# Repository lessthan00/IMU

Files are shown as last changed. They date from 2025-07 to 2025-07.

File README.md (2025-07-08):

# IMU  

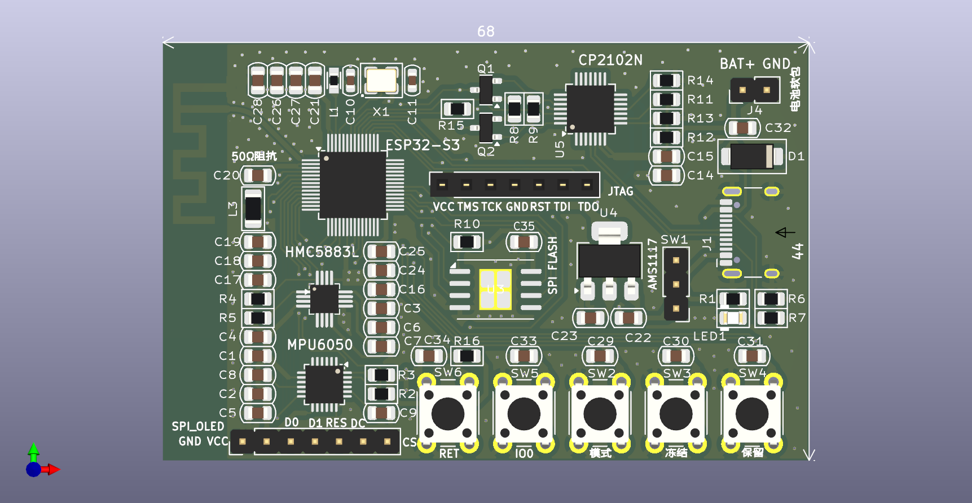
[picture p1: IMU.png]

  
## 基于ESP32的IMU系统与OLED显示屏  
  
### 简介  
  
本项目实现了一个基于ESP32微控制器的惯性测量单元（IMU）系统，集成了MPU6050（6轴加速度计和陀螺仪）、HMC5883L（3轴磁力计）和SSD1306 OLED显示屏（128x64像素）。系统通过卡尔曼滤波融合传感器数据，实时计算并显示设备的俯仰（pitch）、滚转（roll）和偏航（yaw）角度，适用于机器人、无人机或可穿戴设备等需要精确姿态测量的场景。  
  
### 硬件要求  
  
#### 元件清单  
  
| 元件 | 描述 | 备注 |  
|---|---|---|
| ESP32微控制器 | ESP32开发板（如DevKitC）或ESP32S3芯片 | ESP32S3需USB转串口烧录 |  
| MPU6050传感器模块 | 6轴加速度计和陀螺仪 | I2C通信，地址0x68或0x69 |  
| HMC5883L传感器模块 | 3轴数字磁力计 | I2C通信，地址0x1E |  
| SSD1306 OLED显示屏 | 128x64像素 | I2C通信 |  
| 触控按钮（4个） | 用于电源、模式、冻结和预留功能 | 连接到GPIO 15、16、17、18 |  
| 跳线 | 用于连接元件 | |  
| 面包板或PCB | 用于安装元件 | |  
| 电源 | 若不使用带USB的开发板需单独电源 | 3.3V |  
| USB转串口转换器 | 如CP2102或CH340，仅ESP32S3芯片需要 | 用于程序烧录 |  
  
#### 引脚接线图  
  
所有传感器和显示屏通过I2C接口连接到ESP32的GPIO 21（SDA）和GPIO 22（SCL）。按钮连接到指定GPIO引脚。以下是详细接线表：  
  
| 元件 | 引脚 | ESP32连接 | 备注 |  
|---|---|---|---|
| MPU6050 | SDA  | GPIO 11 | I2C数据线 |  
| MPU6050 | SCL  | GPIO 12 | I2C时钟线 |  
| MPU6050 | VCC  | 3.3V | 电源 |  
| MPU6050 | GND  | GND | 接地 |  
| HMC5883L | SDA  | GPIO 11 | I2C数据线 |  
| HMC5883L | SCL  | GPIO 12 | I2C时钟线 |  
| HMC5883L | VCC  | 3.3V | 电源 |  
| HMC5883L | GND  | GND | 接地 |  
| SSD1306 OLED | SDA  | GPIO 11 | I2C数据线 |  
| SSD1306 OLED | SCL  | GPIO 12 | I2C时钟线 |  
| SSD1306 OLED | VCC  | 3.3V | 电源 |  
| SSD1306 OLED | GND  | GND | 接地 |  
| 电源按钮 | - | GPIO 15 | 控制电源开关 |  
| 模式按钮 | - | GPIO 16 | 切换绝对/相对模式 |  
| 冻结按钮 | - | GPIO 17 | 冻结/解冻显示 |  
| 预留按钮 | - | GPIO 18 | 预留未来功能 |  
  
**ESP32S3芯片额外接线**（若使用芯片而非开发板）：  
- TX（ESP32S3）→ RX（USB转串口）  
- RX（ESP32S3）→ TX（USB转串口）  
- CH_PD（ESP32S3）→ 3.3V（USB转串口）  
- EN（ESP32S3）→ 3.3V（USB转串口）  
- GND（ESP32S3）→ GND（USB转串口）  
- VCC（ESP32S3）→ 3.3V（USB转串口）  
  
**注意**：所有I2C设备（MPU6050、HMC5883L、SSD1306）共享相同的SDA和SCL线。按钮连接需使用内部上拉电阻或外部上拉电阻。  
  
### 软件结构  
  
#### 程序结构框图  
  
软件基于FreeRTOS实现多任务处理，包含以下并发任务：  
- **传感器任务**：以20 Hz频率从MPU6050和HMC5883L读取数据，发送到传感器队列。  
- **处理任务**：从传感器队列接收数据，使用卡尔曼滤波计算姿态（俯仰、滚转、偏航），以5 Hz频率发送到姿态队列。  
- **显示任务**：从姿态队列接收数据，以5 Hz频率更新OLED显示屏。  
- **按钮任务**：监控按钮状态，处理电源开关、模式切换（绝对/相对）和显示冻结。  
- **初始化与校准任务**：启动时初始化I2C接口、传感器，并执行校准。  
  
**框图描述**：  
- **输入**：MPU6050（加速度、角速度）、HMC5883L（磁场）  
- **任务流程**：  
  - 传感器任务 → 传感器队列 → 处理任务 → 姿态队列 → 显示任务  
  - 按钮任务 → 处理用户输入  
- **输出**：SSD1306 OLED显示屏  
- **同步机制**：使用FreeRTOS队列（`sensor_queue`、`attitude_queue`）和信号量（`i2c_mutex`、`ssd1306_mutex`、`calibration_done_sem`）进行任务间通信和资源保护。  
  
#### 流程图  
  
1. **启动**：  
   - 初始化ESP32S3外设（I2C、GPIO）  
   - 创建FreeRTOS任务和队列  
2. **校准**：  
   - 校准MPU6050（加速度计和陀螺仪，设备需静止）  
   - 校准HMC5883L（磁力计，需缓慢旋转设备）  
3. **主循环**：  
   - 传感器任务：持续读取传感器数据并发送到队列  
   - 处理任务：从队列接收数据，处理并发送到显示队列  
   - 显示任务：从队列接收数据，更新显示屏  
   - 按钮任务：持续监控按钮并处理事件  
4. **关机**：  
   - 长按电源按钮，暂停任务并关闭系统  
  
### 传感器与显示屏简介  
  
#### MPU6050  
  
MPU6050是一个6轴惯性测量单元，包含3轴加速度计（量程±4g）和3轴陀螺仪（量程±500 dps）。它通过I2C通信（地址0x68或0x69），用于测量设备的俯仰和滚转角度。更多信息可参考 [MPU6050教程](https://www.instructables.com/Connecting-MPU6050-With-ESP32/)。  
  
#### HMC5883L  
  
HMC5883L是一个3轴数字磁力计，用于测量磁场以确定偏航（罗盘方向）。它通过I2C通信（地址0x1E），支持倾斜补偿以提高精度。更多信息可参考 [HMC5883L与ESP32接口](https://circuitdigest.com/microcontroller-projects/diy-smartwatch-using-esp32-part3-interfacing-magnetometer-and-gyroscope-with-esp32)。  
  
#### SSD1306 OLED显示屏  
  
SSD1306是一个128x64像素的OLED显示屏，通过I2C通信，显示实时传感器数据，包括俯仰、滚转、偏航、加速度、陀螺仪和磁力计读数。支持绝对和相对模式，并可根据Z轴加速度自动翻转显示。更多信息可参考 [ESP32与SSD1306教程](https://randomnerdtutorials.com/esp32-ssd1306-oled-display-arduino-ide/)。  
  
### 使用说明  
  
#### 硬件设置  
  
1. 按照引脚接线图连接MPU6050、HMC5883L、SSD1306和按钮到ESP32S3。  
2. 若使用ESP32S3芯片，连接USB转串口模块（TX、RX、CH_PD、EN、GND）。  
3. 使用面包板或PCB固定元件，确保3.3V电源稳定。  
  
#### 程序烧录  
  
1. **使用ESP32S3开发板**：  
   - 通过USB连接开发板到计算机。  
   - 使用ESP-IDF或Arduino IDE（需安装ESP32支持）上传`main.c`程序。  
2. **使用ESP32S3芯片**：  
   - 连接USB转串口模块（如CP2102或CH340）。  
   - 使用ESP-IDF或Arduino IDE烧录程序，确保正确配置串口引脚。  
  
#### 操作  
  
- **开机**：短按电源按钮（GPIO 15）。  
- **关机**：长按电源按钮（>2秒）。  
- **模式切换**：按模式按钮（GPIO 16）切换绝对/相对测量模式。  
- **冻结显示**：按冻结按钮（GPIO 17）冻结/解冻显示。  
- **预留功能**：预留按钮（GPIO 18）为未来功能保留。  
  
### 调试与日志  
  
- 系统使用ESP_LOG框架记录日志，标签为“mpu6050 test”和“SSD1306”。  
- 定期记录任务堆栈使用情况以监控内存使用。  
- 校准期间需保持设备静止（MPU6050）或缓慢旋转（HMC5883L）。  
  
### 当前存在的问题  
  
1. **数据更新速度慢**：  
   - 传感器任务以20 Hz频率生成数据，而处理任务和显示任务以5 Hz频率消费数据，导致生产速度快于消费速度，可能造成`sensor_queue`和`attitude_queue`队列满溢。日志中会记录“传感器队列已满”或“姿态队列已满”的警告。  
   - **潜在解决方案**：优化处理任务的计算效率（如简化卡尔曼滤波算法）或增加队列大小，同时调整任务调度优先级以平衡生产和消费速度。  
  
2. **关机后无法正常开机**：  
   - 系统运行一段时间后，关机（长按电源按钮）并再次短按电源按钮可能无法正常开机，表现为任务未正确恢复或系统未完全初始化。  
   - **潜在原因**：可能是任务挂起/恢复逻辑问题，或电源管理状态未正确重置。需要检查`button_task`中的任务恢复逻辑和硬件电源管理电路。  
  
### 未来展望  
  
1. **添加可视化更好的仪表界面**：  
   - 当前SSD1306显示屏以文本形式显示数据，未来计划开发图形化仪表界面（如指针式仪表或3D姿态可视化），以提高用户体验。  
   - 实现方式可能包括使用SSD1306的图形库绘制动态仪表盘，或升级到更高分辨率的显示屏（如SSD1327或彩色TFT屏）以支持更复杂的可视化。  
   - 需优化显示任务以确保图形渲染不影响实时性能。  
  
## 硬件从新设计  
  
### 物料  
  
GY-521模块,MPU6050,接口定义VCC,GND,SCL,SDA,XDA,SCL,ADO,INT  
GY-271模块,HMC5883L,接口定义VCC,GND,SCL,SDA,DRDY  
轻触开关  
0.96寸OLED SSD1306模块,接口定义VCC,GND,SCL,SDA  
因为I2C总线的通讯拥挤,可以选择使用SPI通讯.  
0.96村OLED SSD1306模块,7针接口定义 GND,VCC,D0,D1,RES,DC,CS  
GND 电源地, VCC 3.3V~5V, D0, SPI时钟线(SPI_CLK), D1,SPI数据线(SPI_MOSI), RES,复位, DC, 数据/命令选择脚,CS,片选信号,低电平有效,CS不可悬空.  
CH340G  
ESP32-S3FN8  
ESP32-S3-WROOM-1-N16R8  
  
### [H/W 硬件参考](https://docs.espressif.com/projects/esp-idf/zh_CN/stable/esp32s3/hw-reference/index.html)  
  
[技术参考手册 (PDF)](https://www.espressif.com/sites/default/files/documentation/esp32-s3_technical_reference_manual_cn.pdf)  
[技术规格书 (PDF)](https://www.espressif.com/sites/default/files/documentation/esp32-s3_datasheet_cn.pdf)  
  
### SPI分配  
  
### [SPI2 管脚对应表](https://docs.espressif.com/projects/esp-idf/zh_CN/stable/esp32s3/api-reference/peripherals/spi_master.html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)  
  
| 管脚名称  | GPIO编号 (SPI2) |  
|---|---|
| CS0 | 10 |  
| SCLK | 12 |  
| MISO | 13 |  
| MOSI | 11 |  
| QUADWP | 14 |  
| QUADHD | 9 |  
  
#### [技术规格书 (PDF)](https://www.espressif.com/sites/default/files/documentation/esp32-s3_datasheet_cn.pdf)  
  
##### 第 30 章 SPI 控制器(SPI)  
  
##### 30.1 概述  
  
串行外设接口(SPI)是一种同步串行接口，可用于与外围设备进行通信。ESP32-S3芯片集成了四个SPI控制  
器：  
• SPI0  
 • SPI1  
 • 通用SPI2，即GP-SPI2  
 • 和通用SPI3，即GP-SPI3  
 SPI0 和 SPI1 控制器主要供内部使用以访问外部flash及PSRAM。本章节主要介绍GP-SPI控制器，即GP-SPI2  
和GP-SPI3。  
  
(所以毫无疑问应该选择SPI2)  
  
##### 30.5.8.3 主机全双工通信（仅支持1-bit模式）  
  
| Master (GP-SPI2) | Direction | Slave  |  
|---|---|---|
| FSPID | → | MOSI |  
| FSPIQ | ← | MISO |  
| FSPICLK | → | CLK |  
| FSPICS0 | → | CS |  
  
##### 附录A–ESP32-S3管脚总览  
  
GPIO9 ~ GPIO14 并未高亮,说明无限制和关键作用,可以放心使用.  
  
### I2C 分配  
  
[技术规格书 (PDF)](https://www.espressif.com/sites/default/files/documentation/esp32-s3_datasheet_cn.pdf)  
  
#### 4.2.1.2 I2C 接口  
  
管脚分配  
I2C 的管脚可以为任意GPIO，通过GPIO交换矩阵配置。  
  
#### 2.3.1 IO MUX 功能  
  
部分直接源自特定外设（U0TXD、MTCK等），包括UART0/1、JTAG、SPI0/1和SPI2  
  
(意味着I2C 并没有不通过IO MUX 矩阵的更特殊接口)  
  
RTC_GPIO0,RTC_GPIO3均被标记为黄色  
  
#### [技术参考手册 (PDF)](https://www.espressif.com/sites/default/files/documentation/esp32-s3_technical_reference_manual_cn.pdf)2.3.4 GPIO 和RTC_GPIO 的限制  
  
本章节的表格中，部分管脚功能有高亮标记。推荐优先使用没有高亮的GPIO或RTC_GPIO管脚。  
如需更多管脚，请谨慎选择高亮的GPIO或RTC_GPIO管脚，避免与重要功能冲突。  
  
#### [技术规格书 (PDF)](https://www.espressif.com/sites/default/files/documentation/esp32-s3_datasheet_cn.pdf)附录A–ESP32-S3管脚总览  
  
可知标黄原因:  
GPIO0,复位时IE,WPU,复位后IE,WPU.  
GPIO3,复位时IE,复位后IE.  
  
#### Boot 模式控制  
  
复位释放后，GPIO0、GPIO1、GPIO2和GPIO46在复位时的值将共同决定Boot模式。表8.2-1列出了GPIO0、  
GPIO1、GPIO2 和 GPIO46 的 Strapping 值及其对应的系统启动模式。  
表8.2-1. 系统启动模式  
  
| Boot Mode | GPIO0 | GPIO46 | GPIO1 | GPIO2 |  
|---|---|---|---|---|
| SPI Boot Mode | 1 | x | x | x |  
| Joint Download Boot Mode| 0 | 0 | x | x |  
| SPI Download Boot Mode  | 0 | 1 | 1 | 0 |  
  
x：任何取值均不会对结果有影响，因此可忽略。  
Joint Download Boot 模式下支持以下下载方式：  
• USB Download Boot  
   –USB-Serial-JTAG Download Boot  
   –USB-OTG Download Boot  
• UART Download Boot  
SPI DownloadBoot模式：GPIO1和GPIO2不是strapping管脚，但使用SPI Download Boot 模式时需要预留GPIO1和GPIO2。GPIO1和GPIO2默认浮空，在复位时处于高阻抗状态。  
  
在SPI Boot 模式下，ROM引导加载程序通过从SPIflash中读取程序来启动系统。SPIBoot模式可进一步细分为以下两种启动方式：  
• 常规flash启动方式：支持安全启动。ROM引导加载程序将程序从flash加载到SRAM，并执行。在大多数实际应用场景中，上述执行的程序多为二级引导程序，该二级引导程序将启动最终的应用程序。  
• 直接启动方式：不支持安全启动，程序直接从flash中运行。如需使能这一启动方式，请确保下载至flash的bin 文件其前两个字（地址：0x42000000）为0xaedb041d。  
在Joint Download Boot 模式下，用户可通过UART或USB接口将二进制文件下载至flash，或将二进制文件下载至SRAM并在SRAM中运行程序。  
在SPI Download Boot 模式下，用户可通过SPI接口将二进制文件下载至flash，或将二进制文件下载至SRAM并运行SRAM中的程序.  
  
所以GPIO0 GPIO1 GPIO2 GPIO3都最好不使用.  
  
#### 管脚配置一栏为复位时和复位后预设配置缩写  
  
•IE–输入使能  
•WPU–内部弱上拉电阻使能  
•WPD–内部弱下拉电阻使能  
• USB_PU–USB上拉电阻使能–USB管脚（GPIO19和GPIO20）默认开启USB功能，此时管脚是否上拉由USB上拉决定。USB上拉由USB_SERIAL_JTAG_DP/  
 DM_PULLUP控制，USB上拉电阻的具体阻值可通过USB_SERIAL_JTAG_PULLUP_VALUE位控制，详见《ESP32-S3技术参考手册》  
>章节USB串口/JTAG控制器。–USB管脚关闭USB功能时，用作普通GPIO，默认禁用管脚内部弱上/下拉电阻，可通过IO_MUX_FUN_WPU/WPD配置，  
详见《ESP32-S3技术参考手册》>章节IOMUX和GPIO交换矩阵。  
EFUSE_DIS_PAD_JTAG的值为  
• 0-弱上拉电阻使能  
• 1-管脚浮空  
  
### SSD1306 7PIN design  
  
[taobao](https://pan.baidu.com/s/1WhZjZDjIXnzRosZPsYRTPA?pwd=6666 )  
  
0.96村OLED SSD1306模块,7针接口定义 GND,VCC,D0,D1,RES,DC,CS  
  
| 引脚名称  | 描述 | 备注 |  
|---|---|---|
| GND | 电源地 | |  
| VCC | 电源 (3.3V~5V) | 工作电压范围 |  
| D0 | SPI时钟线 (SPI_CLK) | |  
| D1 | SPI数据线 (SPI_MOSI) | |  
| RES | 复位信号 | |  
| DC | 数据/命令选择脚 | |  
| CS | 片选信号 (低电平有效) | 不可悬空 |  
  
### MPU6050 design  
  
copy from  [MPU6050](https://github.com/lessthan00/MPU6050)  
  
[JLC 页面](https://www.jlc-smt.com/lcsc/detail?componentCode=C24112)  
  
再次对比原理图封装无问题.  
对比芯片封装也无问题, 引脚间距0.5, QFN4x4mm, 热焊盘2.7x2.7, 打大过孔, 拉长焊盘,好焊接.  
  
[data sheet](https://item.szlcsc.com/datasheet/MPU-6050/24852.html)  
  
#### 描述  
  
其数字运动处理器(DMP)提供的融合运动数据输出，大幅降低了对系统处理器频繁轮询传感器数据的需求。  
1024字节片上FIFO缓冲区通过让系统处理器突发读取传感器数据后进入低功耗模式，有效降低系统整体功耗。  
封装 4x4x0.9mm(QFN)  
MPU-6050仅支持I2C串行接口且设有独立VLOGIC引脚；  
3轴陀螺仪、3轴加速度计及数字运动处理器™(DMP)。通过专用I2C传感器总线，可直接接入外部3轴电子罗盘数据，输出完整的9轴MotionFusion™融合数据。  
  
#### 7.2 Typical Operating Circuit  
  
对比电路图无问题,对比封装,无问题.  
  
I2C 上拉电阻10K  
AD0 下拉到地, 简化电路, 固定I2C 地址.  
FSYNC 帧同步数字输入,不使用下拉到地.  
CLKIN 外部输入时钟信号,不使用下拉到地.  
INT 需要找一个引脚.  
  
#### 9.2 I2C Interface  
  
当MPU-60X0与系统处理器通信时，始终作为从机设备工作（此时系统处理器担任主机角色）。SDA和SCL线路通常需要上拉电阻连接至VDD电源，总线最高传输速率为400kHz。  
  
MPU-60X0的7位从机地址为b110100X，其中最低位（LSB）由AD0引脚的电平状态决定。这一特性支持将两个MPU-60X0设备连接到同一I2C总线：在此配置下，一个设备的地址应为b1101000（AD0引脚置为逻辑低电平），另一个设备的地址则为b1101001（AD0引脚置为逻辑高电平）。  
  
所以I2C地址为 b1101000 (0x68) (104)  
  
#### DMP  
  
MPU-60X0系列芯片内置的数字运动处理器（DMP）可将运动处理算法的计算任务从主处理器卸载。该DMP能够从加速度计、陀螺仪及磁力计等第三方传感器获取数据并进行处理，处理结果既可通过DMP寄存器读取，也可存入FIFO缓冲区。DMP还可调用MPU的一个外部引脚来生成中断信号。  
  
DMP的核心价值在于为主处理器减轻时序处理负担并降低运算负荷。通常情况下，运动处理算法需以约200Hz的高频率运行才能保证低延迟的精确运算——即便应用层更新速率低至5Hz（如低功耗用户界面场景）也不例外。采用DMP可有效实现四大优势：降低系统功耗、简化时序控制、优化软件架构，并为应用程序节省宝贵的主处理器运算资源。  
  
(进一步了解发现好像DMP也没那么好用)  
  
### HMC5883L design  
  
[嘉立创 开发板模块资料](https://wiki.lckfb.com/zh-hans/esp32s3r8n8/module/sensor/hmc5883l-sensor.html)  
[采购链接](https://detail.tmall.com/item.htm?abbucket=15&id=615355218813&ns=1)  
[HMC5883L资料下载链接](https://pan.baidu.com/s/1DfYH5OQHmD8zj1fMbI6ffg) 提取码：8888  
[数据手册](https://cdn-shop.adafruit.com/datasheets/HMC5883L_3-Axis_Digital_Compass_IC.pdf)  
  
#### HMC5883L description  
  
sch copy from [QMC5883L](https://github.com/lessthan00/QMC5883L)  
  
霍尼韦尔 HMC5883L 是一种表面贴装的高集成模块，并带有数字接口的弱磁传感器芯片，应用于低成本罗盘和磁场检测领域。HMC5883L 包括最先进的高分辨率 HMC118X 系列磁阻传感器，并附带霍尼韦尔专利的集成电路包括放大器、自动消磁驱动器、偏差校准、能使罗盘精度控制在 1°~2°的 12 位模数转换器.简易的 I2C 系列总线接口。HMC5883L 是采用无铅表面封装技术，带有16引脚，尺寸为3.0X3.0X0.9mm。  
低电压工作(2.16-3.6V)和超低功耗（100uA）  
最大输出频率可达160Hz  
  
#### 供电压选择  
  
如果选择1.8V 供电, 会导致IO口需要转电平  
3.3V 供电是可行的,所以选择3.3V供电.  
  
#### I2C 地址转换表  
  
| 地址类型 | 十六进制格式 | 二进制格式 | 十进制格式 |  
|---|---|---|---|
| 7位设备地址 | 0x1E | `b001 1110` | 30 |  
| 8位读取地址 | 0x3D | `b0011 1101` | 61 |  
| 8位写入地址 | 0x3C | `b0011 1100` | 60 |  
  
##### 7位地址 → 8位地地址  
  
- 7位地址直接使用低7位  
- 8位地址在7位地址前补0，并在末尾添加R/W位：  
- **写入地址** = (7位地址 << 1) | 0  
   `0x1E << 1` = 0x3C  
   `0x3C | 0` = 0x3C  
- **读取地址** = (7位地址 << 1) | 1  
   `0x1E << 1` = 0x3C  
   `0x3C | 1` = 0x3D  
  
#### 引脚配置  
  
| 引脚编号 | 引脚名称 | 描述 |  
|---|---|---|
| 1 | SCL | 串行时钟 - I2C总线主/从时钟 |  
| 2 | VDD | 电源（2.16V-3.6V） |  
| 3 | NC | 无连接 |  
| 4 | S1 | 连接 VDDIO |  
| 5 | NC | 无连接 |  
| 6 | NC | 无连接 |  
| 7 | NC | 无连接 |  
| 8 | SETP | 置位/复位带正-S/R电容（C2）连接 |  
| 9 | GND | 电源接地 |  
| 10 | C1 | 存储电容器（C1）连接 |  
| 11 | GND | 电源接地 |  
| 12 | SETC | S/R电容器（C2）连接-驱动端 |  
| 13 | VDDIO | IO电源供应（1.7V-VDD） |  
| 14 | NC | 无连接 |  
| 15 | DRDY | 数据准备，中断引脚。内部被拉高。当数据位于输出寄存器时会在低电位上停250μsec |  
| 16 | SDA | 串行数据 - I2C总线主/从数据 |  
  
### 按照推荐电路图设计  
  
I2C上拉电阻选择为10K  
  
### QMC5883L design  
  
这是HMC5883L的替代,引脚配置是一样的,封装也是一样的 LGA-16(3x3),轴的方向也一样,外围电路图也是一样.  
  
[QMC5883L JLC](https://www.jlc-smt.com/lcsc/detail?componentCode=C976032&spm=smt-pc.search-result.list.1)  
  
#### QMC5883L description  
  
QMC5883L 是一款多芯片三轴磁传感器。这款表面贴装、小尺寸芯片集成了磁传感器与信号调理专用集成电路（ASIC），主要面向无人机、机器人、移动设备及手持装置等高精度应用场景，如电子罗盘、导航和游戏交互。  
  
基于霍尼韦尔（Honeywell）授权的先进磁阻（AMR）技术，QMC5883L结合定制设计的16位模数转换器（ADC）ASIC，具有低噪声、高精度、低功耗、偏移消除和温度补偿等优势，可实现1°至2°的罗盘航向精度。其I²C串行总线接口便于快速集成。  
  
该传感器采用3x3x0.9mm³的16引脚栅格阵列（LGA）表面贴装封装。  
  
低电压工作(2.16-3.6V)和超低功耗（75uA）  
最大输出频率可达200Hz  

## 打板需要注意板厚

### RF要求50Ω共面单端阻抗

2层板 板厚1.6 铜厚1OZ  
线宽 19.8110mil 覆铜间距5mil

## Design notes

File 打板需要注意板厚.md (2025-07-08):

# RF要求50Ω共面单端阻抗

2层板 板厚1.6 铜厚1OZ 
线宽 19.8110mil 覆铜间距5mil

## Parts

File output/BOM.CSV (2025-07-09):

位号 | 数值 | 封装 | 数量
AE1 | PCB_ANT |  | 1
AE2 | PCB_ANT | Library:ANT-2_4G-Top-2 | 1
C1,C27 | 10nF | PCM_Capacitor_SMD_AKL:C_0805_2012Metric | 2
C2,C3,C4,C5,C8,C15,C16,C19,C20,C21,C25,C29,C30,C31,C32,C33,C35 | 100nF | PCM_Capacitor_SMD_AKL:C_0805_2012Metric | 17
C6 | 220nF | PCM_Capacitor_SMD_AKL:C_0805_2012Metric | 1
C7,C14 | 4.7uF | PCM_Capacitor_SMD_AKL:C_0805_2012Metric | 2
C9 | 2.2nF | PCM_Capacitor_SMD_AKL:C_0805_2012Metric | 1
C10,C11 | 15pF | PCM_Capacitor_SMD_AKL:C_0603_1608Metric | 2
C12,C13 | 1.8pF | PCM_Capacitor_SMD_AKL:C_0805_2012Metric | 2
C17,C26 | 10uF | PCM_Capacitor_SMD_AKL:C_0805_2012Metric | 2
C18,C24,C28,C34 | 1uF | PCM_Capacitor_SMD_AKL:C_0805_2012Metric | 4
C22,C23 | 22uF | PCM_Capacitor_SMD_AKL:C_0805_2012Metric | 2
D1 | SMAJ6.5CA | PCM_Diode_SMD_AKL:D_SMA_TVS | 1
J1 | USB_C_Receptacle_USB2.0_16P | Connector_USB:USB_C_Receptacle_HCTL_HC-TYPE-C-16P-01A | 1
J2 | Conn_01x08 | Connector_PinHeader_2.54mm:PinHeader_1x08_P2.54mm_Vertical | 1
J3 | Conn_01x07 | Connector_PinSocket_2.54mm:PinSocket_1x07_P2.54mm_Vertical | 1
J4 | Conn_01x02 | Connector_PinHeader_2.54mm:PinHeader_1x02_P2.54mm_Vertical | 1
L1 | 24 nH (3%), 140 mA | PCM_4ms_Resistor:R_0603 | 1
L2 | 24nH | PCM_Resistor_SMD_AKL:R_1206_3216Metric | 1
L3 | 2.0 nH 600 mA | PCM_Resistor_SMD_AKL:R_1206_3216Metric | 1
LED1 | 5Vred | PCM_LED_SMD_AKL:LED_0805_2012Metric | 1
Q1,Q2 | SS8050 | Package_TO_SOT_SMD:SOT-23 | 2
R1,R11 | 2K | PCM_Resistor_SMD_AKL:R_0805_2012Metric | 2
R2,R3,R4,R5,R8,R9,R16 | 10K | PCM_Resistor_SMD_AKL:R_0805_2012Metric | 7
R6,R7 | 5.1K | PCM_Resistor_SMD_AKL:R_0805_2012Metric | 2
R10,R14 | 10K(NC) | PCM_Resistor_SMD_AKL:R_0805_2012Metric | 2
R12 | 22.1K | PCM_Resistor_SMD_AKL:R_0805_2012Metric | 1
R13 | 47.5K | PCM_Resistor_SMD_AKL:R_0805_2012Metric | 1
R15 | 499R | PCM_Resistor_SMD_AKL:R_0805_2012Metric | 1
SW1 | SW_SPDT | Connector_PinHeader_2.54mm:PinHeader_1x03_P2.54mm_Vertical | 1
SW2,SW3,SW4,SW5,SW6 | SW_Push | Button_Switch_THT:SW_PUSH_6mm_H7.3mm | 5
U1 | HMC5883L | Library:LGA-16_3x3mm_P0.5mm | 1
U2 | MPU-6050 | Library:QFN-24-1EP_4x4mm_P0.5mm_EP2.7x2.7mm_ThermalVias | 1
U3 | W25Q128JVE | Library:WSON-8-1EP_8x6mm_P1.27mm_EP3.4x4.3mm | 1
U4 | AMS1117-3.3 | Package_TO_SOT_SMD:SOT-223-3_TabPin2 | 1
U5 | CP2102N-Axx-xQFN28 | Library:QFN-28-1EP_5x5mm_P0.5mm_EP3.35x3.35mm | 1
U6 | ESP32-S3 | Library:QFN-56-1EP_7x7mm_P0.4mm_EP5.6x5.6mm | 1
X1 | 40MHz(±10ppm) | PCM_Crystal_AKL:Crystal_SMD_3225-4Pin_3.2x2.5mm | 1

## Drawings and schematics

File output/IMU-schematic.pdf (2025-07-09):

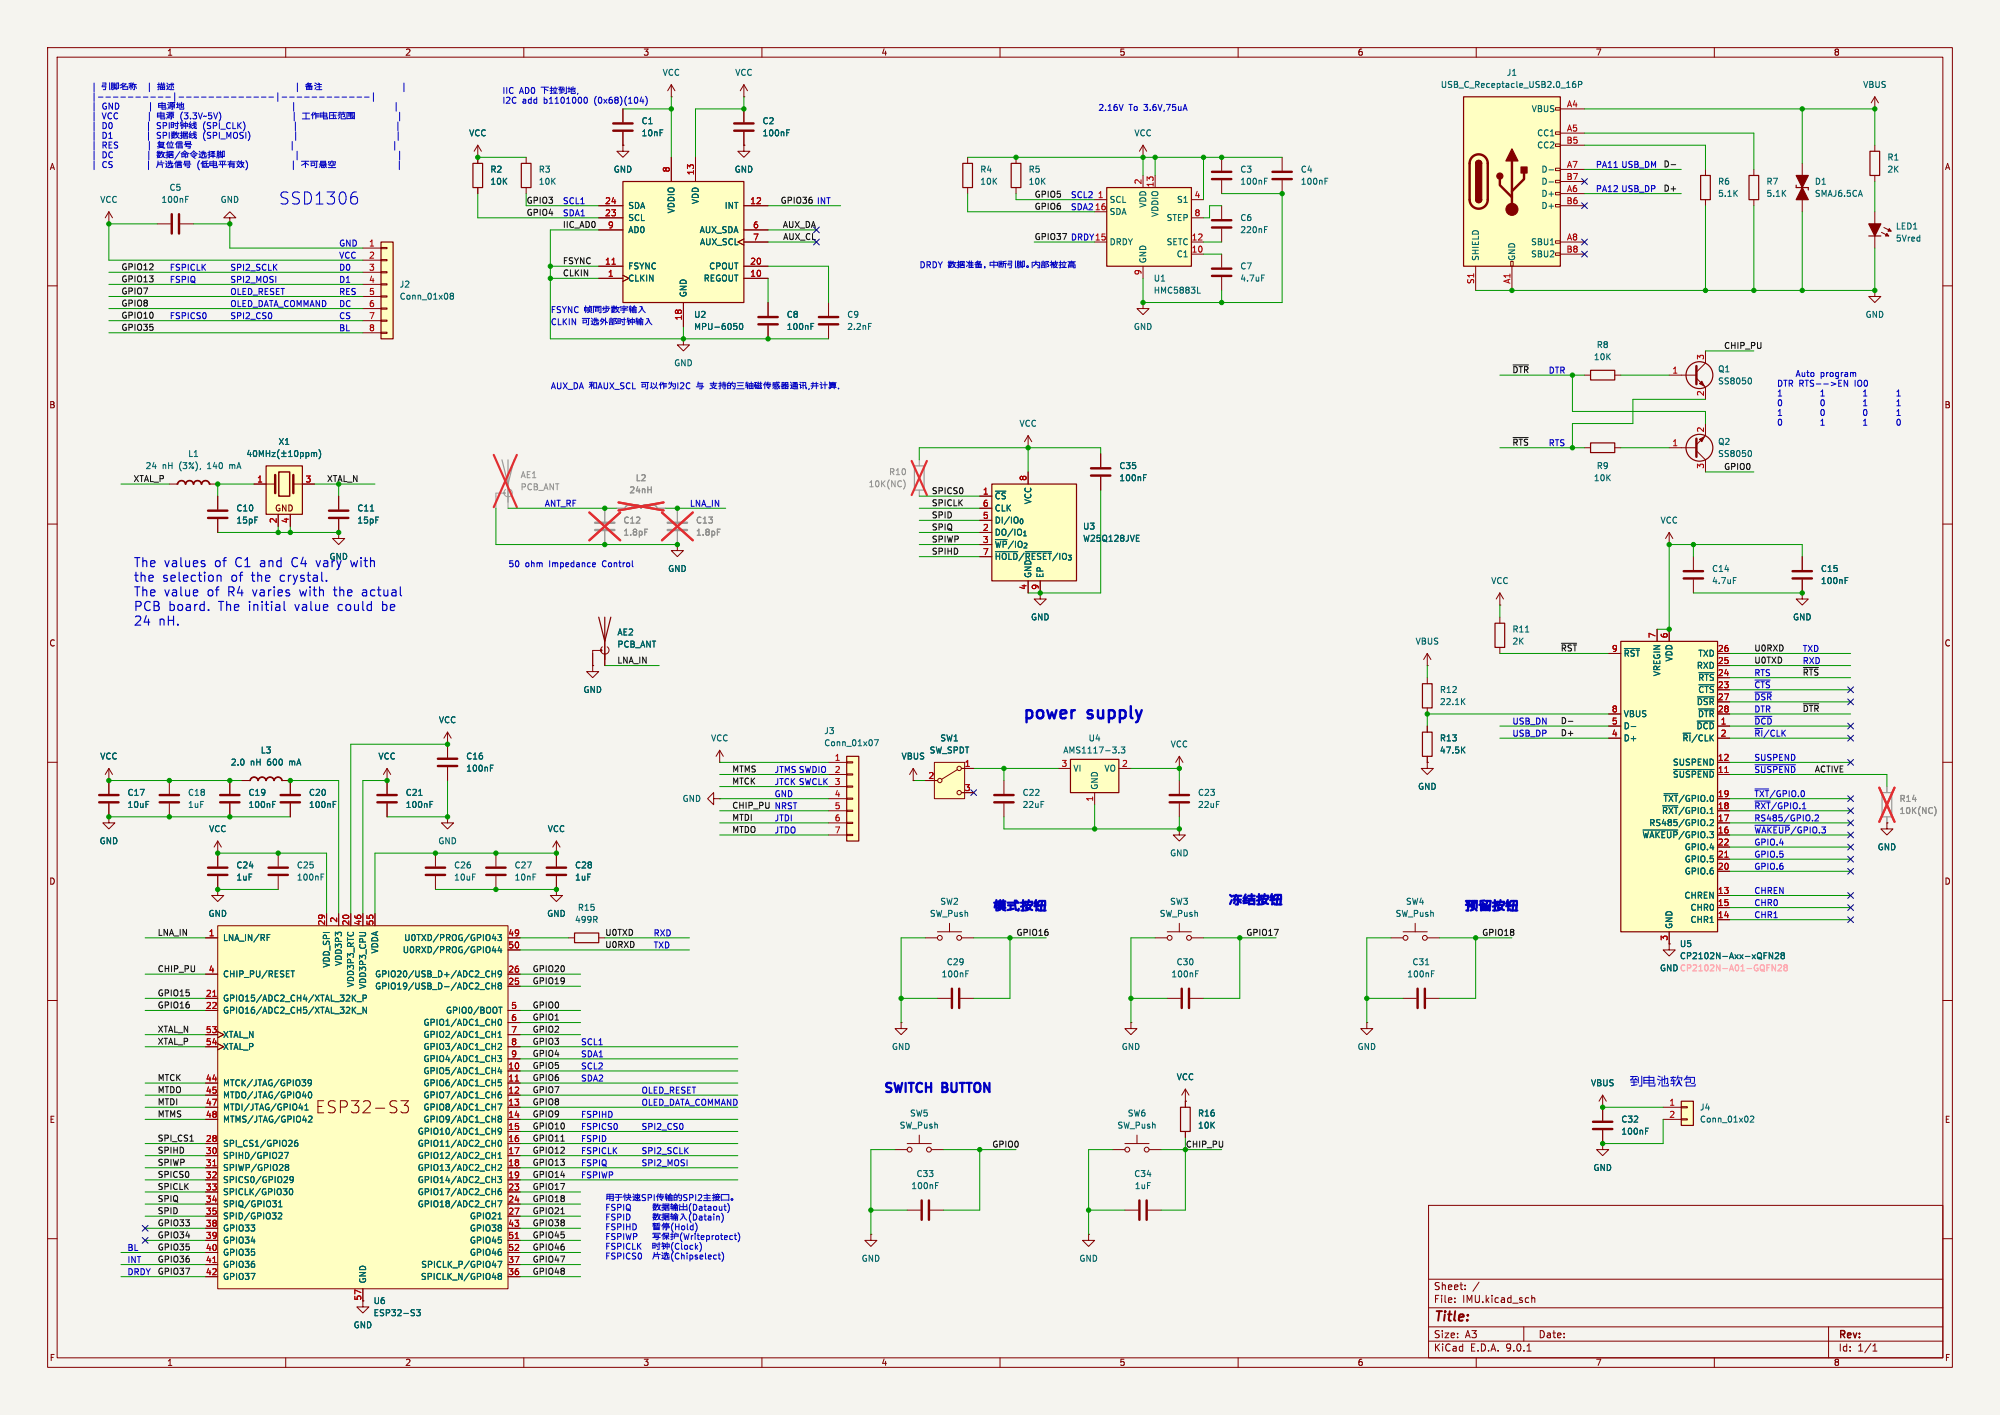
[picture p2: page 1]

FSYNC þÿ^'Tkeep[W•“Qe CLKIN þÿSï• Y•èeö”Ÿ•“Qe

DTR The values of C1 and C4 vary with

The value of R4 varies with the actual

26 RXD
25 ~{RTS} 24 ~{CTS} 23 ~{DSR} 27 ~{DTR} 28 ~{DCD}1 ~{RI}/CLK

RS485/GPIO.2 ~{TXT}/GPIO.0 SUSPEND
~{SUSPEND}

2 VDD3P3_RTC 20 VDD3P3_CPU 46 GND 57 VDDA 55 U0TXD/PROG/GPIO43 49 U0RXD/PROG/GPIO44 50 GPIO20/USB_D+/ADC2_CH9 26 GPIO19/USB_D-/ADC2_CH8 25 GPIO0/BOOT 5 GPIO1/ADC1_CH0 6 GPIO2/ADC1_CH1 7 GPIO3/ADC1_CH2 8 GPIO4/ADC1_CH3 9 GPIO5/ADC1_CH4 10 GPIO6/ADC1_CH5 11 GPIO7/ADC1_CH6 12 GPIO8/ADC1_CH7 13 GPIO9/ADC1_CH8 14 GPIO10/ADC1_CH9 15 GPIO11/ADC2_CH0 16 GPIO12/ADC2_CH1 17 GPIO13/ADC2_CH2 18 GPIO14/ADC2_CH3 19 GPIO17/ADC2_CH6 23 GPIO18/ADC2_CH7 24 GPIO21 27 GPIO38 43 GPIO45 51 GPIO46 52 U6ESP32-S3 GND

2 VDD3P3_RTC 20 VDD3P3_CPU 46 GND 57 VDDA 55 U0TXD/PROG/GPIO43 49 U0RXD/PROG/GPIO44 50 GPIO20/USB_D+/ADC2_CH9 26 GPIO19/USB_D-/ADC2_CH8 25 GPIO0/BOOT 5 GPIO1/ADC1_CH0 6 GPIO2/ADC1_CH1 7 GPIO3/ADC1_CH2 8 GPIO4/ADC1_CH3 9 GPIO5/ADC1_CH4 10 GPIO6/ADC1_CH5 11 GPIO7/ADC1_CH6 12 GPIO8/ADC1_CH7 13 GPIO9/ADC1_CH8 14 GPIO10/ADC1_CH9 15 GPIO11/ADC2_CH0 16 GPIO12/ADC2_CH1 17 GPIO13/ADC2_CH2 18 GPIO14/ADC2_CH3 19 GPIO17/ADC2_CH6 23 GPIO18/ADC2_CH7 24 GPIO21 27 GPIO38 43 GPIO45 51 GPIO46 52 GND

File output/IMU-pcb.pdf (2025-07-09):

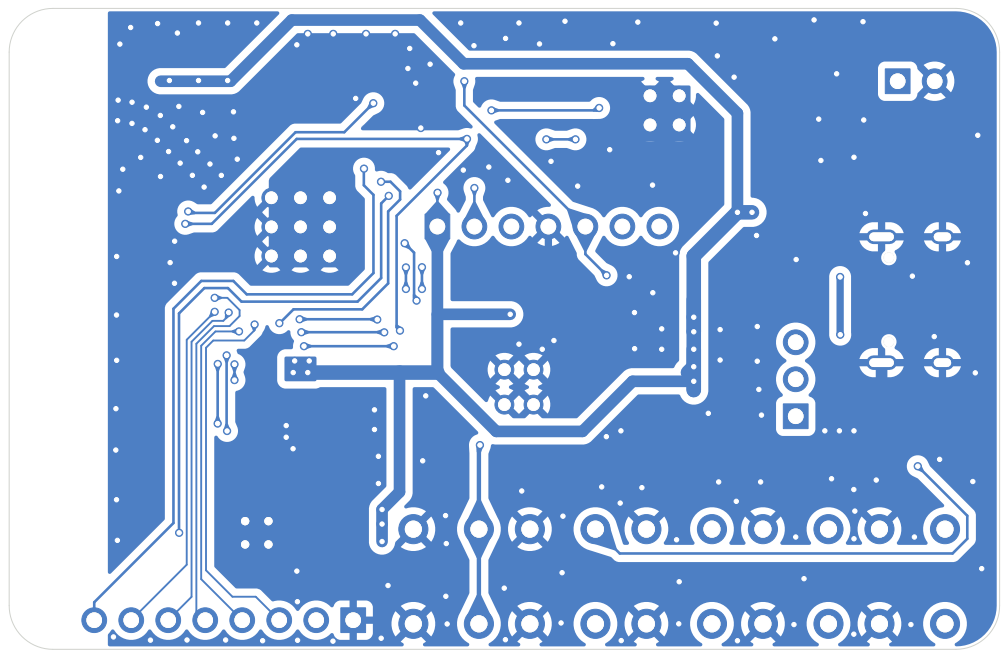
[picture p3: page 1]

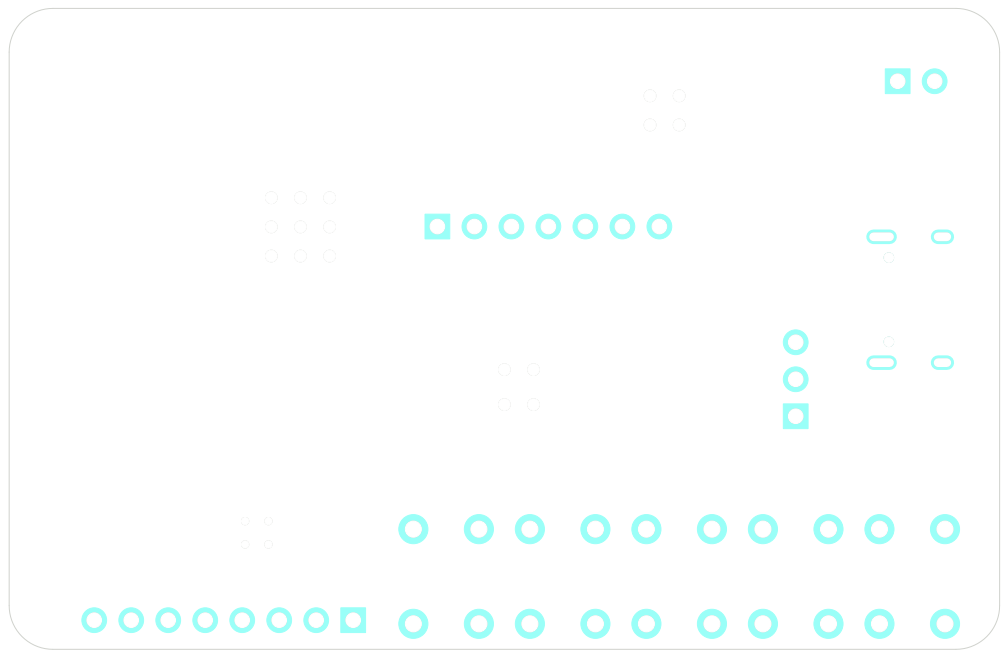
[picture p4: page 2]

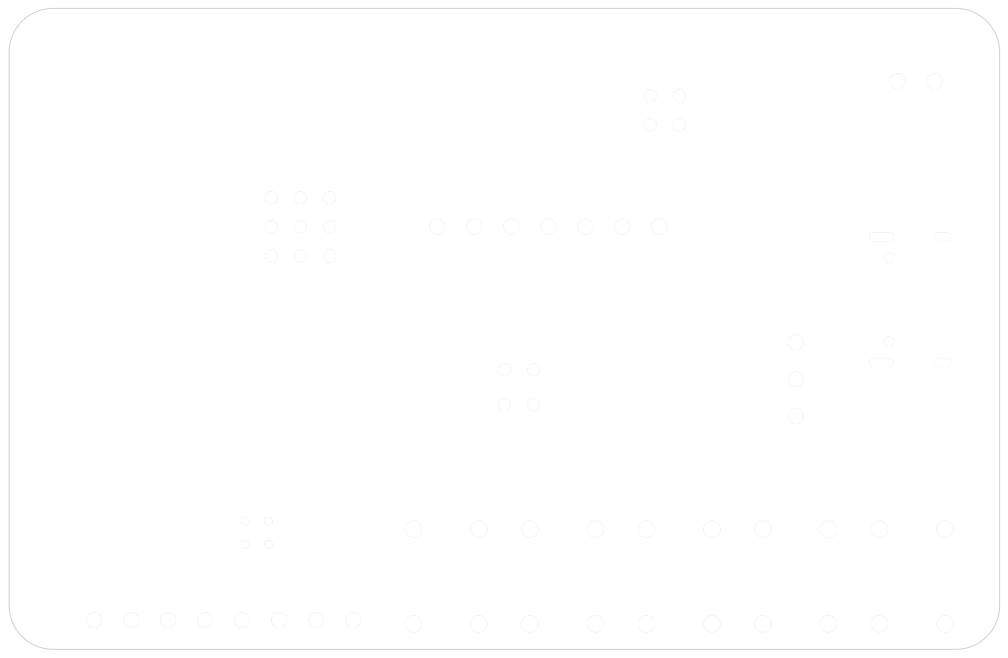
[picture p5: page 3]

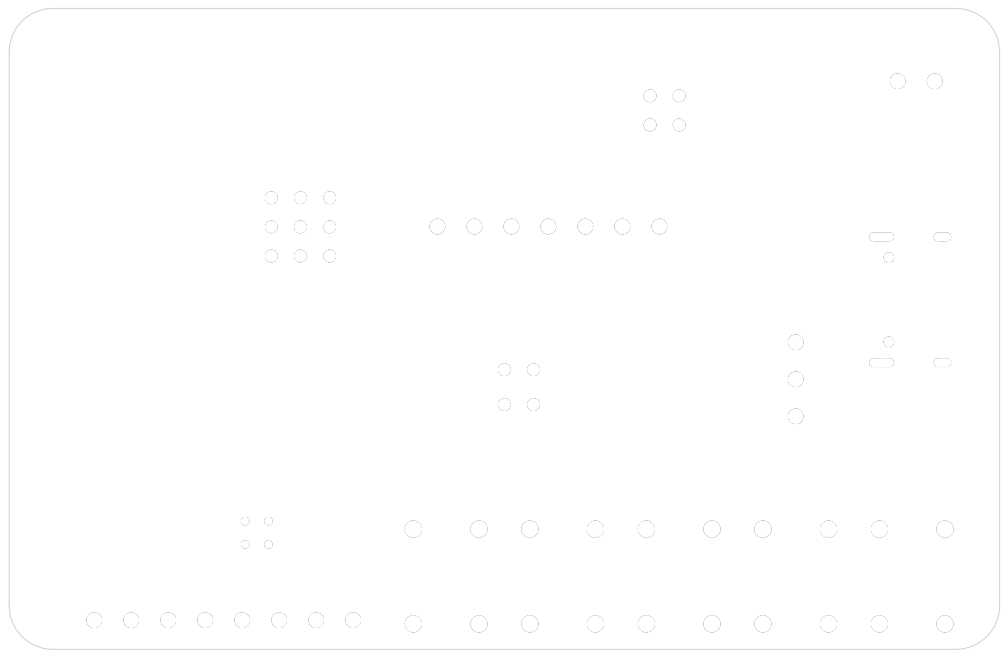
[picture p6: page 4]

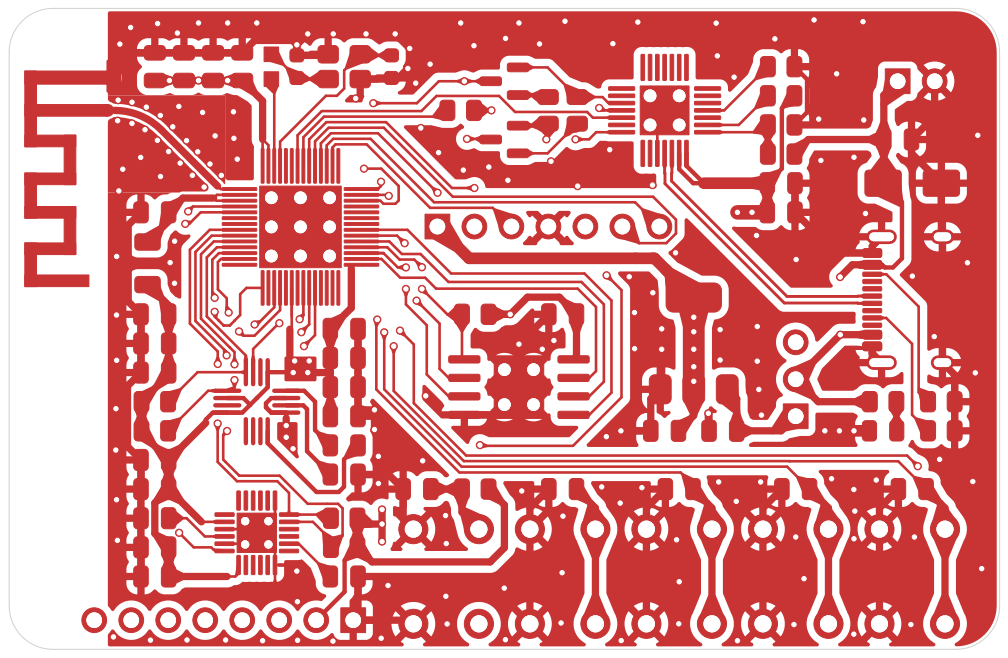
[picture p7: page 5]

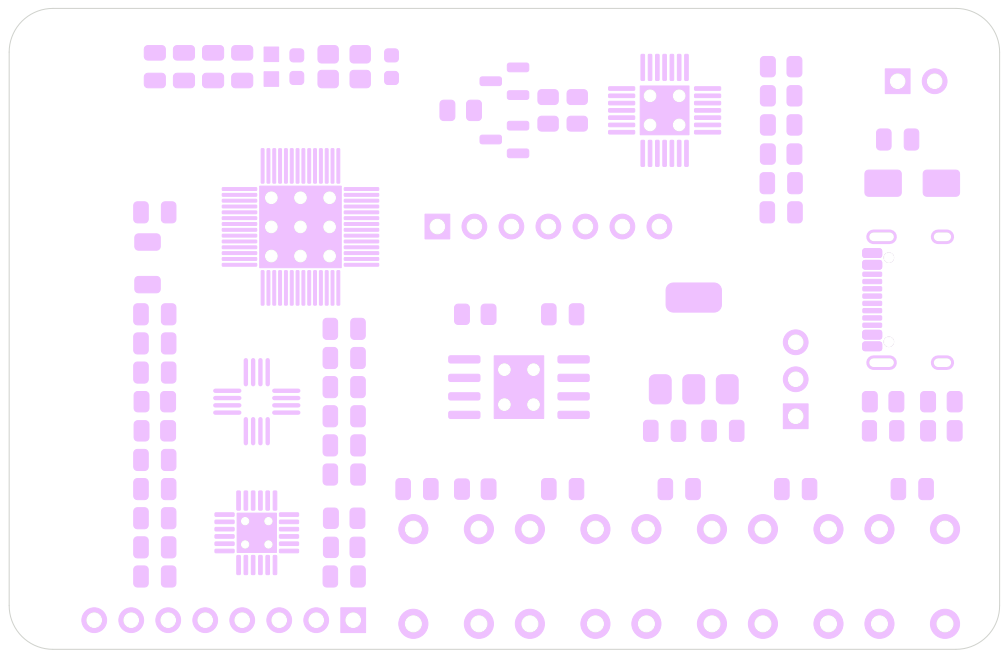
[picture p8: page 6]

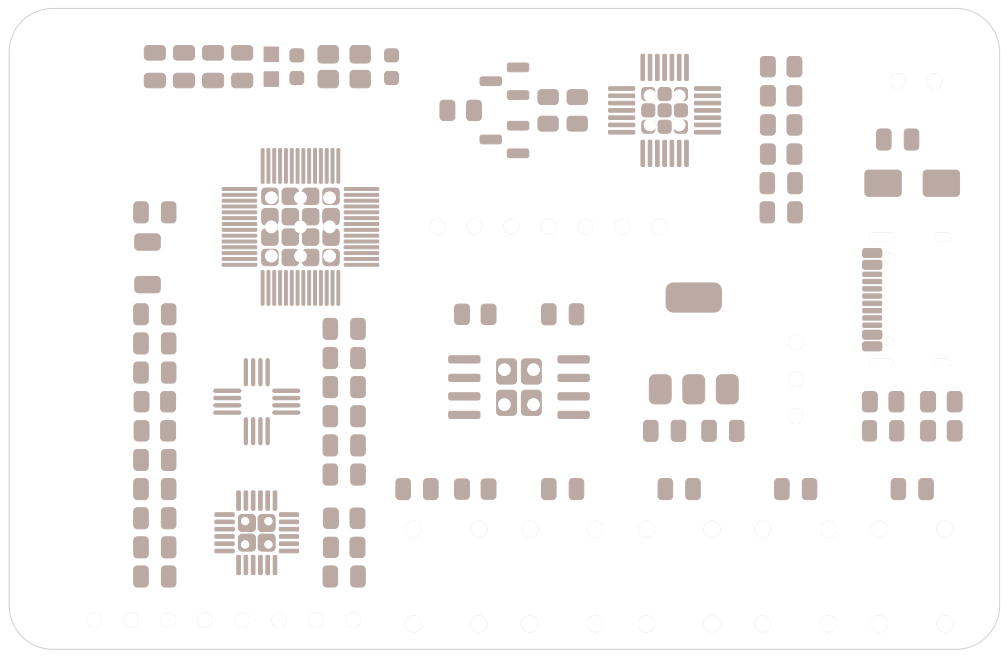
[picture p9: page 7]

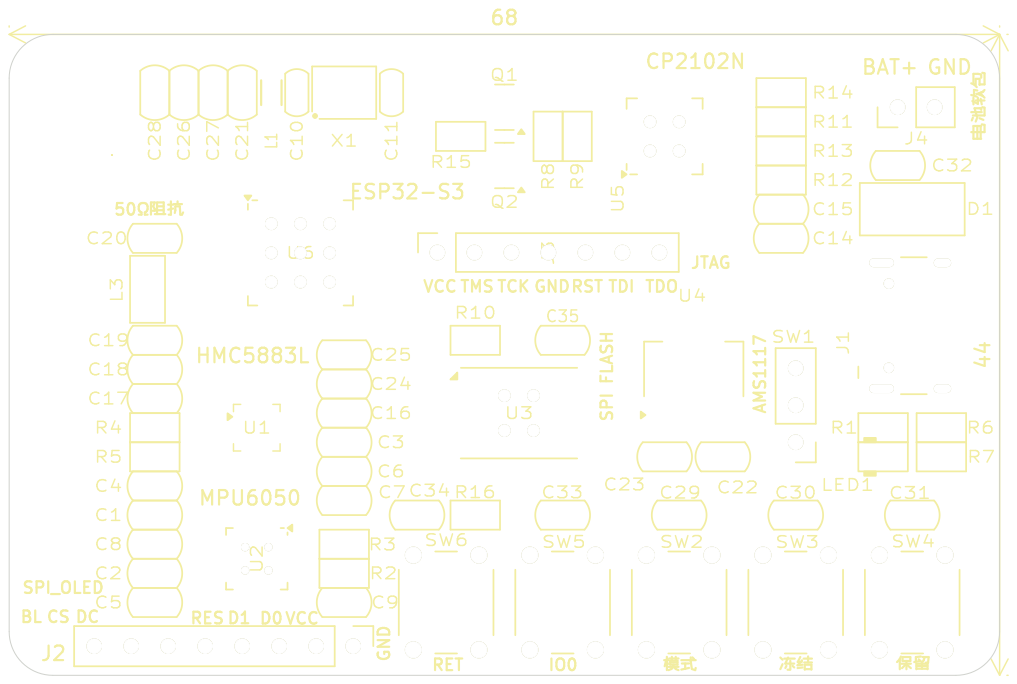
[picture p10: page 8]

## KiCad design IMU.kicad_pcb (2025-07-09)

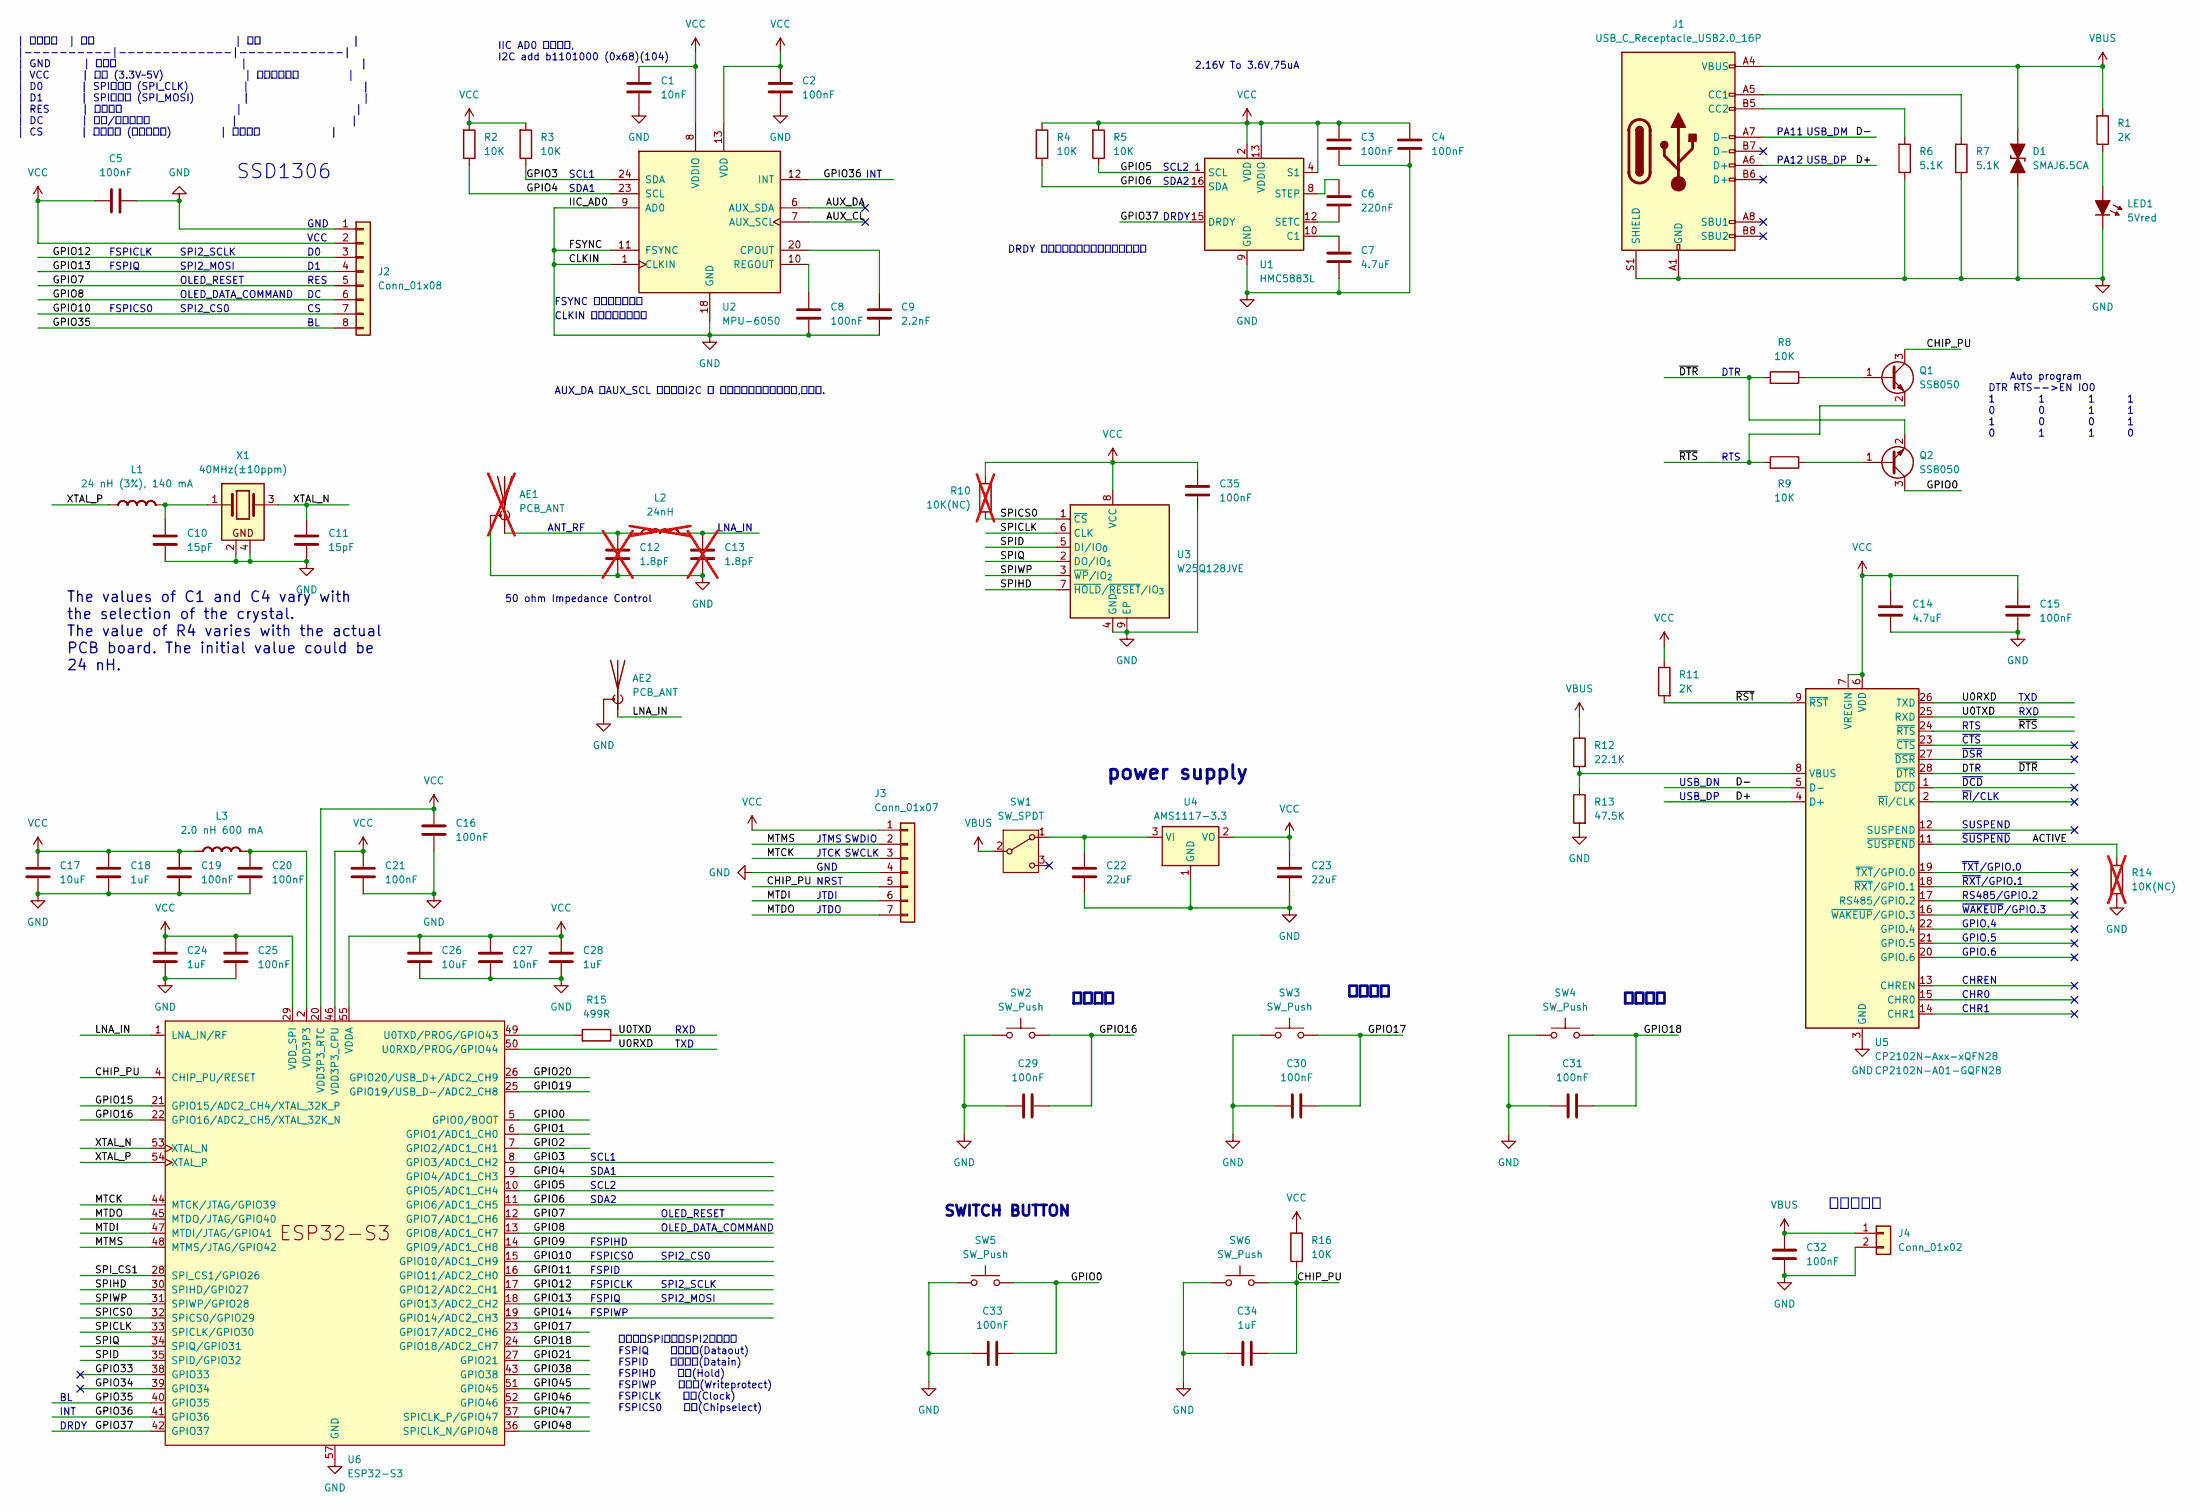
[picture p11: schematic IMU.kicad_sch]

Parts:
AE1: PCB_ANT; not fitted
AE2: PCB_ANT; ANT-2_4G-Top-2
C1, C27: 10nF; C_0805_2012Metric
C2, C3, C4, C5, C8, C15, C16, C19, C20, C21, C25, C29, C30, C31, C32, C33, C35: 100nF; C_0805_2012Metric
C6: 220nF; C_0805_2012Metric
C7, C14: 4.7uF; C_0805_2012Metric
C9: 2.2nF; C_0805_2012Metric
C10, C11: 15pF; C_0603_1608Metric
C12, C13: 1.8pF; C_0805_2012Metric; not fitted
C17, C26: 10uF; C_0805_2012Metric
C18, C24, C28, C34: 1uF; C_0805_2012Metric
C22, C23: 22uF; C_0805_2012Metric
D1: SMAJ6.5CA; D_SMA_TVS
J1: USB_C_Receptacle_USB2.0_16P; USB_C_Receptacle_HCTL_HC-TYPE-C-16P-01A
J2: Conn_01x08; PinHeader_1x08_P2.54mm_Vertical
J3: Conn_01x07; PinSocket_1x07_P2.54mm_Vertical
J4: Conn_01x02; PinHeader_1x02_P2.54mm_Vertical
L1: 24 nH (3%), 140 mA; R_0603; Rating A
L2: 24nH; R_1206_3216Metric; Rating A; not fitted
L3: 2.0 nH 600 mA; R_1206_3216Metric; Rating A
LED1: 5Vred; LED_0805_2012Metric
Q1, Q2: SS8050; SOT-23
R1, R11: 2K; R_0805_2012Metric
R2, R3, R4, R5, R8, R9, R16: 10K; R_0805_2012Metric
R6, R7: 5.1K; R_0805_2012Metric
R10, R14: 10K(NC); R_0805_2012Metric; not fitted
R12: 22.1K; R_0805_2012Metric
R13: 47.5K; R_0805_2012Metric
R15: 499R; R_0805_2012Metric
SW1: SW_SPDT; PinHeader_1x03_P2.54mm_Vertical
SW2, SW3, SW4, SW5, SW6: SW_Push; SW_PUSH_6mm_H7.3mm
U1: HMC5883L; LGA-16_3x3mm_P0.5mm
U2: MPU-6050; QFN-24-1EP_4x4mm_P0.5mm_EP2.7x2.7mm_ThermalVias
U3: W25Q128JVE; WSON-8-1EP_8x6mm_P1.27mm_EP3.4x4.3mm
U4: AMS1117-3.3; SOT-223-3_TabPin2
U5: CP2102N-Axx-xQFN28; QFN-28-1EP_5x5mm_P0.5mm_EP3.35x3.35mm
U6: ESP32-S3; QFN-56-1EP_7x7mm_P0.4mm_EP5.6x5.6mm
X1: 40MHz(±10ppm); Crystal_SMD_3225-4Pin_3.2x2.5mm

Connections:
/ACTIVE: R14.2, U5.11 (~SUSPEND)
/AUX_CL: U2.7 (AUX_SCL)
/AUX_DA: U2.6 (AUX_SDA)
/CHIP_PU: C34.1, J3.5, Q1.3 (C), R16.2, SW6.2, U6.4 (CHIP_PU/RESET)
/D+: J1.A6 (D+), U5.4 (D+)
/D-: J1.A7 (D-), U5.5 (D-)
/GPIO0: C33.1, Q2.3 (C), SW5.2, U6.5 (GPIO0/BOOT)
/GPIO1: U6.6 (GPIO1/ADC1_CH0)
/GPIO2: U6.7 (GPIO2/ADC1_CH1)
/GPIO3: R3.2, U2.24 (SDA), U6.8 (GPIO3/ADC1_CH2)
/GPIO4: R2.2, U2.23 (SCL), U6.9 (GPIO4/ADC1_CH3)
/GPIO5: R5.2, U1.1 (SCL), U6.10 (GPIO5/ADC1_CH4)
/GPIO6: R4.2, U1.16 (SDA), U6.11 (GPIO6/ADC1_CH5)
/GPIO7: J2.5, U6.12 (GPIO7/ADC1_CH6)
/GPIO8: J2.6, U6.13 (GPIO8/ADC1_CH7)
/GPIO9: U6.14 (GPIO9/ADC1_CH8)
/GPIO10: J2.7, U6.15 (GPIO10/ADC1_CH9)
/GPIO11: U6.16 (GPIO11/ADC2_CH0)
/GPIO12: J2.3, U6.17 (GPIO12/ADC2_CH1)
/GPIO13: J2.4, U6.18 (GPIO13/ADC2_CH2)
/GPIO14: U6.19 (GPIO14/ADC2_CH3)
/GPIO15: U6.21 (GPIO15/ADC2_CH4/XTAL_32K_P)
/GPIO16: C29.1, SW2.2, U6.22 (GPIO16/ADC2_CH5/XTAL_32K_N)
/GPIO17: C30.1, SW3.2, U6.23 (GPIO17/ADC2_CH6)
/GPIO18: C31.1, SW4.2, U6.24 (GPIO18/ADC2_CH7)
/GPIO19: U6.25 (GPIO19/USB_D-/ADC2_CH8)
/GPIO20: U6.26 (GPIO20/USB_D+/ADC2_CH9)
/GPIO21: U6.27 (GPIO21)
/GPIO33: U6.38 (GPIO33)
/GPIO34: U6.39 (GPIO34)
/GPIO35: J2.8, U6.40 (GPIO35)
/GPIO36: U2.12 (INT), U6.41 (GPIO36)
/GPIO37: U1.15 (DRDY), U6.42 (GPIO37)
/GPIO38: U6.43 (GPIO38)
/GPIO45: U6.51 (GPIO45)
/GPIO46: U6.52 (GPIO46)
/GPIO47: U6.37 (SPICLK_P/GPIO47)
/GPIO48: U6.36 (SPICLK_N/GPIO48)
/LNA_IN: AE2.1 (A), U6.1 (LNA_IN/RF)
/MTCK: J3.3, U6.44 (MTCK/JTAG/GPIO39)
/MTDI: J3.6, U6.47 (MTDI/JTAG/GPIO41)
/MTDO: J3.7, U6.45 (MTDO/JTAG/GPIO40)
/MTMS: J3.2, U6.48 (MTMS/JTAG/GPIO42)
/SPICLK: U3.6 (CLK), U6.33 (SPICLK/GPIO30)
/SPICS0: R10.1, U3.1 (~CS), U6.32 (SPICS0/GPIO29)
/SPID: U3.5 (DI/IO_{0}), U6.35 (SPID/GPIO32)
/SPIHD: U3.7 (~HOLD/~RESET/IO_{3}), U6.30 (SPIHD/GPIO27)
/SPIQ: U3.2 (DO/IO_{1}), U6.34 (SPIQ/GPIO31)
/SPIWP: U3.3 (~WP/IO_{2}), U6.31 (SPIWP/GPIO28)
/SPI_CS1: U6.28 (SPI_CS1/GPIO26)
/U0RXD: U5.26 (TXD), U6.50 (U0RXD/PROG/GPIO44)
/U0TXD: R15.2, U5.25 (RXD)
/XTAL_N: C11.1, U6.53 (XTAL_N), X1.3
/XTAL_P: L1.1 (+), U6.54 (XTAL_P)
/~DTR: Q2.2 (E), R8.1, U5.28 (~DTR)
/~RST: R11.1, U5.9 (~RST)
/~RTS: Q1.2 (E), R9.1, U5.24 (~RTS)
GND: AE1.2 (Shield), AE2.2 (Shield), C1.2, C2.2, C3.2, C4.2, C5.2, C7.2, C8.1, C9.2, C10.2, C11.2, C12.2, C13.2, C14.2, C15.2, C16.2, C17.2, C18.2, C19.2, C20.2, C21.2, C22.2, C23.2, C24.2, C25.2, C26.2, C27.2, C28.2, C29.2, C30.2, C31.2, C32.2, C33.2, C34.2, C35.2, D1.1 (K), J1.A1 (GND), J1.A12 (GND), J1.B1 (GND), J1.B12 (GND), J1.S1 (SHIELD), J2.1, J3.4, J4.2, LED1.1 (K), R6.2, R7.2, R13.1, R14.1, SW2.1, SW3.1, SW4.1, SW5.1, SW6.1, U1.9 (GND), U1.11 (GND), U2.1 (CLKIN), U2.9 (AD0), U2.11 (FSYNC), U2.18 (GND), U2.25 (GND), U3.4 (GND), U3.9 (EP), U4.1 (GND), U5.3 (GND), U5.29 (GND), U6.57 (GND), X1.2, X1.4
unnamed: AE1.1 (A), C12.1, L2.1 (+)
unnamed: C13.1, L2.2 (-)
unnamed: J1.A5 (CC1), R7.1
unnamed: J1.B5 (CC2), R6.1
unnamed: C10.1, L1.2 (-), X1.1
unnamed: LED1.2 (A), R1.2
unnamed: Q1.1 (B), R8.2
unnamed: Q2.1 (B), R9.2
unnamed: C22.1, SW1.1 (A), U4.3 (VI)
unnamed: C7.1, U1.10 (C1)
unnamed: C6.2, U1.12 (SETC)
unnamed: C6.1, U1.8 (STEP)
unnamed: C9.1, U2.20 (CPOUT)
unnamed: C8.2, U2.10 (REGOUT)
unnamed: R12.1, R13.2, U5.8 (VBUS)
unnamed: R15.1, U6.49 (U0TXD/PROG/GPIO43)
VBUS: C32.1, D1.2 (A), J1.A4 (VBUS), J1.A9 (VBUS), J1.B4 (VBUS), J1.B9 (VBUS), J4.1, R1.1, R12.2, SW1.2 (B)
VCC: C1.1, C2.1, C3.1, C4.1, C5.1, C14.1, C15.1, C16.1, C17.1, C18.1, C19.1, C21.1, C23.1, C24.1, C25.1, C26.1, C27.1, C28.1, C35.1, J2.2, J3.1, L3.1 (+), R2.1, R3.1, R4.1, R5.1, R10.2, R11.2, R16.1, U1.2 (VDD), U1.4 (S1), U1.13 (VDDIO), U2.8 (VDDIO), U2.13 (VDD), U3.8 (VCC), U4.2 (VO), U5.6 (VDD), U5.7 (VREGIN), U6.20 (VDD3P3_RTC), U6.29 (VDD_SPI), U6.46 (VDD3P3_CPU), U6.55 (VDDA), U6.56 (VDDA)
VDD3P3: C20.1, L3.2 (-), U6.2 (VDD3P3), U6.3 (VDD3P3)

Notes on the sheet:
FSPICLK
AUX_DA 和AUX_SCL 可以作为I2C 与 支持的三轴磁传感器通讯,并计算.
PA12
DTR
RTS
TXD
SCL1
PA11
GND
JTDO
INT
GPIO.5
FSPICS0
SDA2
OLED_DATA_COMMAND
FSYNC 帧同步数字输入
RXD
Auto program DTR RTS-->EN IO0 1 1 1 1 0 0 1 1 1 0 0 1 0 1 1 0
IIC AD0 下拉到地, I2C add b1101000 (0x68)(104)
USB_DM
VCC
RS485/GPIO.2
SWDIO
RES
SPI2_CS0
JTDI
到电池软包
SPI2_SCLK
CLKIN 可选外部时钟输入
USB_DP
FSPIQ
~{WAKEUP}/GPIO.3
CHREN
DRDY
模式按钮
~{TXT}/GPIO.0
SUSPEND
LNA_IN
ANT_RF
FSPIWP

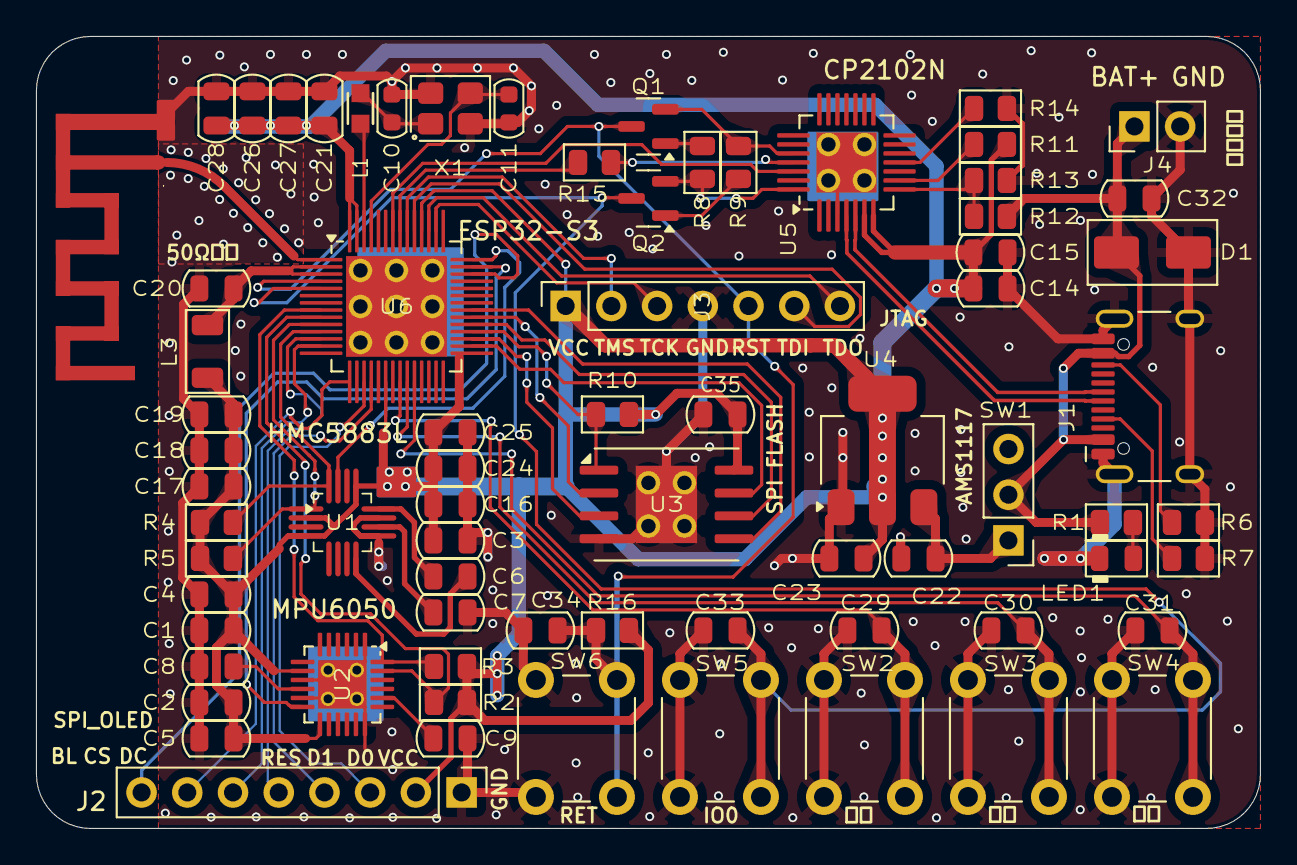
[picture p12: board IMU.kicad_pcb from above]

Board: 2 copper layers, 68.0 x 44.0 mm, 73 parts (0 on the bottom side), 56 nets.
